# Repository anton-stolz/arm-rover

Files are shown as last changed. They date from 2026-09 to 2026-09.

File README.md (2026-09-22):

# Arm Rover



## Features
For now it can drive to specified positions on its map.

## Map



## Hardware

The Chassis is build with wood bars and a lot of hot glue

- RaspberryPi 4
- Arduino Uno
- 2D Lidar ld d500
- imu: mpu6500
- 5v 2A UBEC, 5v 8A UBEC
- DC Motor controller build from spare parts: Mosfet Transistor, logic Transistor and Relay
- Geard TT-Motors with wheels
- Hall Sensors 49E
- Battery: 2200mAh LiPo

## Wheel Encoders
Custom designed and 3d Printed magnetic encoder using 4 2x5mm Neodym magnets, aranged in a 4 Pole encoder.

## Bumper Sensor
the lidar is mounted relatively high, so there is a danger of bumping into stuff thats below the line of sight of the lidar sensor.
The Bumper sensors are the cardboard sheets in the front of back which are mounted with foam at the lower end, so it compresses, and using hall sensors this movement can be detected.  

## Software

all of this glue code is mostly written by LLMs, \
my contribution is the Integration, and actually making it work.

## In Progress: Robot Arm



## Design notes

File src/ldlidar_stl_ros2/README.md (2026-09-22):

- [cn](#操作指南)
- [en](#Instructions)
# 操作指南

>此SDK仅适用于深圳乐动机器人有限公司销售的激光雷达产品，产品型号为:
> - LDROBOT LiDAR LD06
> - LDROBOT LiDAR LD19
> - LDROBOT LiDAR STL-27L

## 0. 获取雷达的ROS2功能包
```bash
cd ~

mkdir -p ldlidar_ros2_ws/src

cd ldlidar_ros2_ws/src

git clone  https://github.com/ldrobotSensorTeam/ldlidar_stl_ros2.git
```
## 1. 系统设置
- 第一步，通过板载串口或者USB转串口模块(例如,cp2102模块)的方式使雷达连接到你的系统主板.
- 第二步，设置雷达在系统中挂载的串口设备-x权限(以/dev/ttyUSB0为例)
	- 实际使用时，根据雷达在你的系统中的实际挂载情况来设置，可以使用`ls -l /dev`命令查看.

``` bash
cd ~/ldlidar_ros2_ws

sudo chmod 777 /dev/ttyUSB0
```
- 第三步，修改`launch/`目录下雷达产品型号对应的lanuch文件中的`port_name`值，以`ld06.launch.py` 和 `/dev/ttyUSB0`为例，如下所示.

```py
#!/usr/bin/env python3
from launch import LaunchDescription
from launch_ros.actions import Node

'''
Parameter Description:
---
- Set laser scan directon: 
  1. Set counterclockwise, example: {'laser_scan_dir': True}
  2. Set clockwise,        example: {'laser_scan_dir': False}
- Angle crop setting, Mask data within the set angle range:
  1. Enable angle crop fuction:
    1.1. enable angle crop,  example: {'enable_angle_crop_func': True}
    1.2. disable angle crop, example: {'enable_angle_crop_func': False}
  2. Angle cropping interval setting:
  - The distance and intensity data within the set angle range will be set to 0.
  - angle >= 'angle_crop_min' and angle <= 'angle_crop_max' which is [angle_crop_min, angle_crop_max], unit is degress.
    example:
      {'angle_crop_min': 135.0}
      {'angle_crop_max': 225.0}
      which is [135.0, 225.0], angle unit is degress.
'''

def generate_launch_description():
  # LDROBOT LiDAR publisher node
  ldlidar_node = Node(
      package='ldlidar_stl_ros2',
      executable='ldlidar_stl_ros2_node',
      name='LD06',
      output='screen',
      parameters=[
        {'product_name': 'LDLiDAR_LD06'},
        {'topic_name': 'scan'},
        {'frame_id': 'base_laser'},
        {'port_name': '/dev/ttyUSB0'},
        {'port_baudrate': 230400},
        {'laser_scan_dir': True},
        {'enable_angle_crop_func': False},
        {'angle_crop_min': 135.0},
        {'angle_crop_max': 225.0}
      ]
  )

  # base_link to base_laser tf node
  base_link_to_laser_tf_node = Node(
    package='tf2_ros',
    executable='static_transform_publisher',
    name='base_link_to_base_laser_ld06',
    arguments=['0','0','0.18','0','0','0','base_link','base_laser']
  )

  # Define LaunchDescription variable
  ld = LaunchDescription()

  ld.add_action(ldlidar_node)
  ld.add_action(base_link_to_laser_tf_node)

  return ld
```
## 2. 编译方法

使用colcon编译.

```bash
cd ~/ldlidar_ros2_ws

colcon build
```
## 3. 运行方法
### 3.1. 设置功能包环境变量

- 编译完成后需要将编译生成的相关文件加入环境变量，便于 ROS 环境可以识别， 执行命令如下所示， 该命令是临时给终端加入环境变量，意味着您如果重新打开新的终端，也需要重新执行如下命令.

  ```bash
  cd ~/ldlidar_ros2_ws

  source install/setup.bash
  ```
- 为了重新打开终端后，永久不用执行上述添加环境变量的命令，可以进行如下操作.

  ```bash
  echo source ~/ldlidar_ros2_ws/install/setup.bash >> ~/.bashrc

  source ~/.bashrc
  ```
### 3.2. 启动激光雷达节点

- 产品型号为 LDROBOT LiDAR LD06
  - 启动ld06 lidar node:
  ``` bash
  ros2 launch ldlidar_stl_ros2 ld06.launch.py
  ```
  - 启动ld06 lidar node并显示激光数据在Rviz2上:
  ``` bash
  ros2 launch ldlidar_stl_ros2 viewer_ld06.launch.py
  ```

- 产品型号为 LDROBOT LiDAR LD19
  - 启动ld19 lidar node:
  ``` bash
  ros2 launch ldlidar_stl_ros2 ld19.launch.py
  ```
  - 启动ld19 lidar node并显示激光数据在Rviz2上:
  ``` bash
  ros2 launch ldlidar_stl_ros2 viewer_ld19.launch.py
  ```
  
- 产品型号为 LDROBOT LiDAR STL-27L
  - 启动stl27l lidar node:
  ``` bash
  ros2 launch ldlidar_stl_ros2 stl27l.launch.py
  ```
  - 启动stl27l lidar node并显示激光数据在Rviz2上:
  ``` bash
  ros2 launch ldlidar_stl_ros2 viewer_stl27l.launch.py
  ```

##   4. 测试

> 代码支持ubuntu20.04 ROS2 foxy版本及以上测试，使用rviz2可视化。
- 新打开一个终端 (Ctrl + Alt + T),运行命令:`rviz2`,并通过Rviz2工具打开readme文件所在目录的rviz2文件夹下面的ldlidar.rviz文件
```bash
rviz2
```

# Instructions

> This SDK is only applicable to the LiDAR products sold by Shenzhen LDROBOT Co., LTD. The product models are :
> - LDROBOT LiDAR LD06
> - LDROBOT LiDAR LD19
> - LDROBOT LiDAR STL-27L

## step 0: get LiDAR ROS2 Package
```bash
cd ~

mkdir -p ldlidar_ros2_ws/src

cd ldlidar_ros2_ws/src

git clone  https://github.com/ldrobotSensorTeam/ldlidar_stl_ros2.git
```
## step 1: system setup
- Connect the LiDAR to your system motherboard via an onboard serial port or usB-to-serial module (for example, CP2102 module).

- Set the -x permission for the serial port device mounted by the radar in the system (for example, /dev/ttyUSB0)

  - In actual use, the LiDAR can be set according to the actual mounted status of your system, you can use 'ls -l /dev' command to view.

``` bash
cd ~/ldlidar_ros2_ws

sudo chmod 777 /dev/ttyUSB0
```
- Modify the `port_name` value in the Lanuch file corresponding to the radar product model under `launch/`, using `ld06.launch.py` and `/dev/ttyUSB0` as an example, as shown below.

```py
#!/usr/bin/env python3
from launch import LaunchDescription
from launch_ros.actions import Node

'''
Parameter Description:
---
- Set laser scan directon: 
  1. Set counterclockwise, example: {'laser_scan_dir': True}
  2. Set clockwise,        example: {'laser_scan_dir': False}
- Angle crop setting, Mask data within the set angle range:
  1. Enable angle crop fuction:
    1.1. enable angle crop,  example: {'enable_angle_crop_func': True}
    1.2. disable angle crop, example: {'enable_angle_crop_func': False}
  2. Angle cropping interval setting:
  - The distance and intensity data within the set angle range will be set to 0.
  - angle >= 'angle_crop_min' and angle <= 'angle_crop_max' which is [angle_crop_min, angle_crop_max], unit is degress.
    example:
      {'angle_crop_min': 135.0}
      {'angle_crop_max': 225.0}
      which is [135.0, 225.0], angle unit is degress.
'''

def generate_launch_description():
  # LDROBOT LiDAR publisher node
  ldlidar_node = Node(
      package='ldlidar_stl_ros2',
      executable='ldlidar_stl_ros2_node',
      name='LD06',
      output='screen',
      parameters=[
        {'product_name': 'LDLiDAR_LD06'},
        {'topic_name': 'scan'},
        {'frame_id': 'base_laser'},
        {'port_name': '/dev/ttyUSB0'},
        {'port_baudrate': 230400},
        {'laser_scan_dir': True},
        {'enable_angle_crop_func': False},
        {'angle_crop_min': 135.0},
        {'angle_crop_max': 225.0}
      ]
  )

  # base_link to base_laser tf node
  base_link_to_laser_tf_node = Node(
    package='tf2_ros',
    executable='static_transform_publisher',
    name='base_link_to_base_laser_ld06',
    arguments=['0','0','0.18','0','0','0','base_link','base_laser']
  )

  # Define LaunchDescription variable
  ld = LaunchDescription()

  ld.add_action(ldlidar_node)
  ld.add_action(base_link_to_laser_tf_node)

  return ld
```

## step 2: build

Run the following command.

```bash
cd ~/ldlidar_ros2_ws

colcon build
```
## step 3: run

### step3.1: package environment variable settings

- After the compilation is completed, you need to add the relevant files generated by the compilation to the environment variables, so that the ROS environment can recognize them. The execution command is as follows. This command is to temporarily add environment variables to the terminal, which means that if you reopen a new terminal, you also need to re-execute it. The following command.
  
  ```bash
  cd ~/ldlidar_ros2_ws
  
  source install/setup.bash
  ```
  
- In order to never need to execute the above command to add environment variables after reopening the terminal, you can do the following.

  ```bash
  echo source ~/ldlidar_ros2_ws/install/setup.bash >> ~/.bashrc
  
  source ~/.bashrc
  ```
### step3.2: start LiDAR node

- The product is LDROBOT LiDAR LD06
  - start ld06 lidar node:
  ``` bash
  ros2 launch ldlidar_stl_ros2 ld06.launch.py
  ```
  - start ld06 lidar node and show on the Rviz2:
  ``` bash
  ros2 launch ldlidar_stl_ros2 viewer_ld06.launch.py
  ```

- The product is LDROBOT LiDAR LD19
  - start ld19 lidar node:
  ``` bash
  ros2 launch ldlidar_stl_ros2 ld19.launch.py
  ```
  - start ld19 lidar node and show on the Rviz2:
  ``` bash
  ros2 launch ldlidar_stl_ros2 viewer_ld19.launch.py
  ```
  
- The product is LDROBOT LiDAR STL-27L
  - start stl27l lidar node:
  ``` bash
  ros2 launch ldlidar_stl_ros2 stl27l.launch.py
  ```
  - start stl27l lidar node and show on the Rviz2:
  ``` bash
  ros2 launch ldlidar_stl_ros2 viewer_stl27l.launch.py
  ```

## step 4: test

> The code supports ubuntu 20.04 ros2 foxy version and above, using rviz2 visualization.

- new a terminal (Ctrl + Alt + T) and use Rviz2 tool(run command: `rviz2`) ,open the `ldlidar.rviz` file below the rviz2 folder of the readme file directory
```bash
rviz2
```
# arm-rover

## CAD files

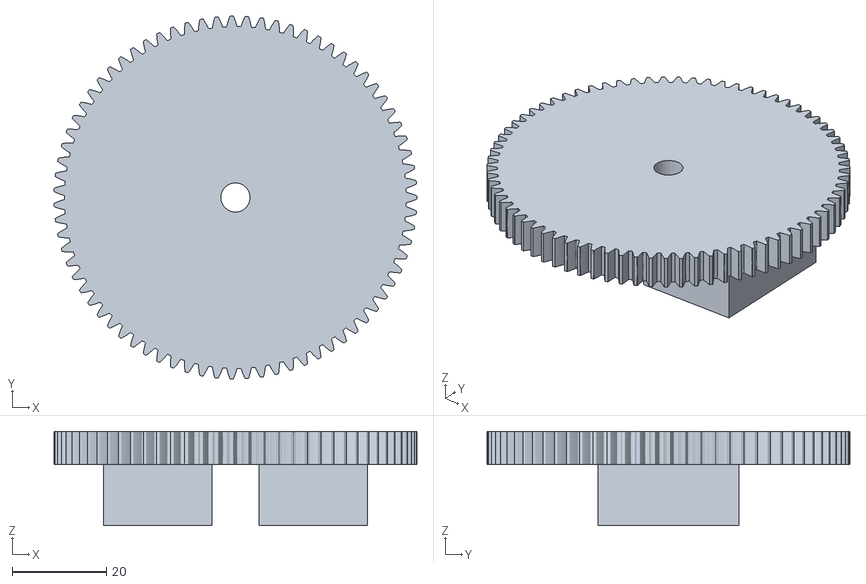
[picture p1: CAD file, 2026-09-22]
hardware/robot_arm/big_gear_with_wood_holder.stl
77.0 x 77.0 x 20.0

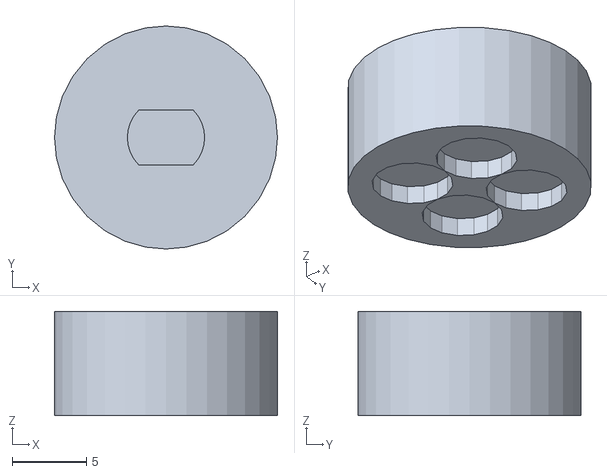
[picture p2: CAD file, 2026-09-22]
hardware/wheel_encoder/hall_wheel.stl
15.0 x 15.0 x 7.00

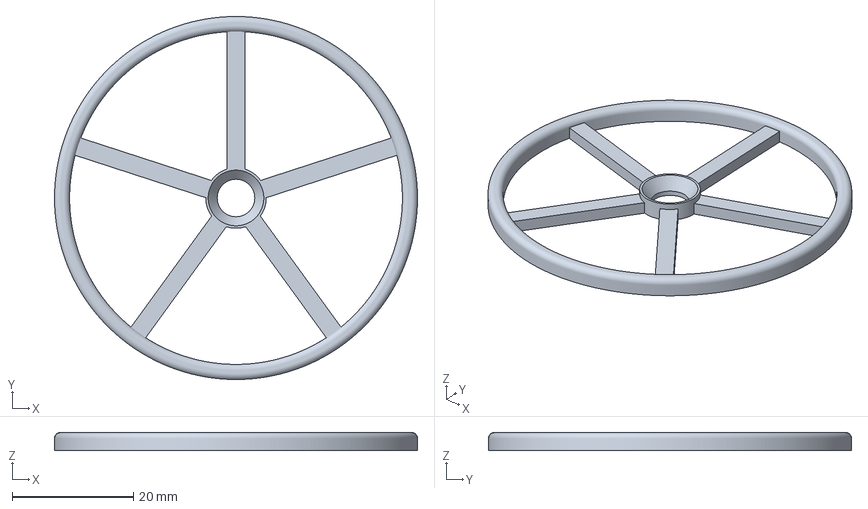
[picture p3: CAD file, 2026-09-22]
hardware/robot_arm/joint1_friction_circle-BodyChamfer.3mf
60.0 x 60.0 x 3.00 mm

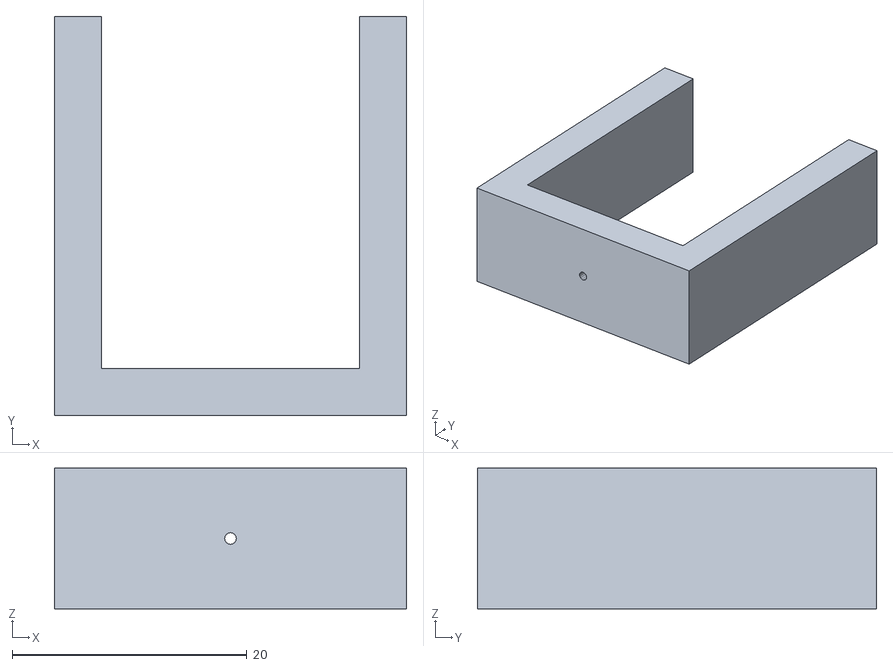
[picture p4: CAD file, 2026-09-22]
hardware/wheel_encoder/hall_holder.stl
30.0 x 34.0 x 12.0

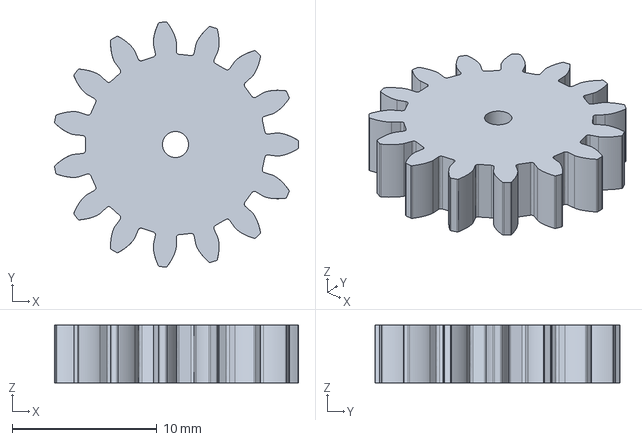
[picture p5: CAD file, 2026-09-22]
hardware/robot_arm/servo_gear.FCStd
16.9 x 16.9 x 4.00 mm

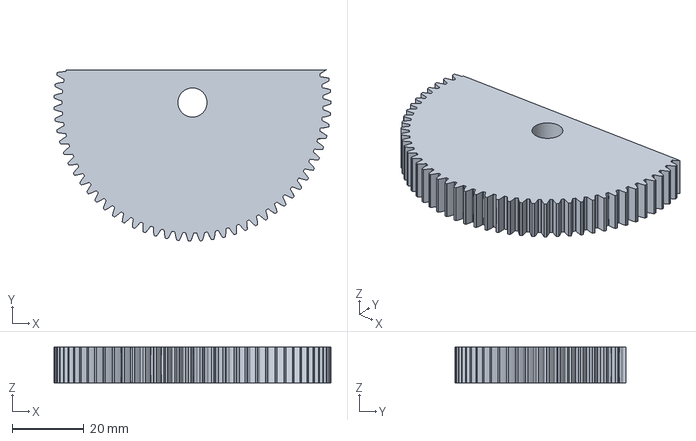
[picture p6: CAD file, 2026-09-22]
hardware/robot_arm/joint2.FCStd
77.0 x 47.5 x 10.0 mm

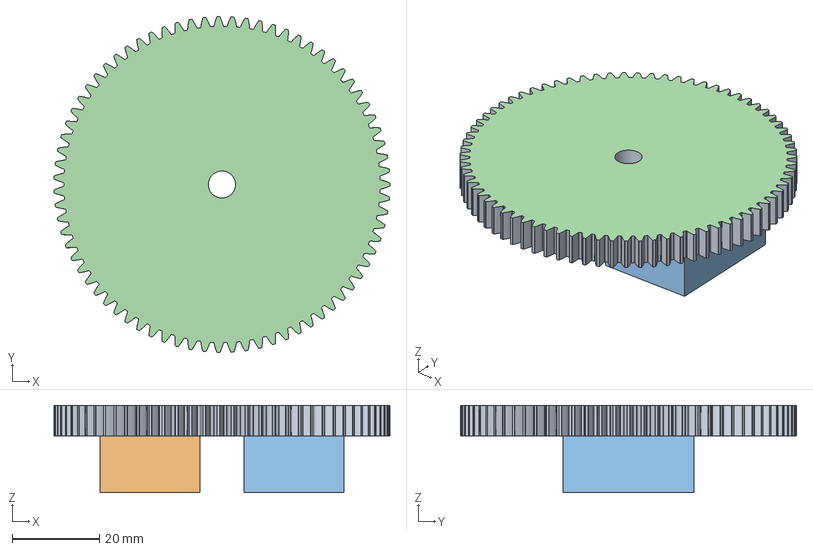
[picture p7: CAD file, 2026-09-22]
hardware/robot_arm/arm.FCStd
77.0 x 77.0 x 20.0 mm
gear_big
Extrude (Mirror #1)
ReferenceInvoluteGear001

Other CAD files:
hardware/robot_arm/joint1_friction_circle.FCStd
hardware/robot_arm/servo_gear-Cut.3mf

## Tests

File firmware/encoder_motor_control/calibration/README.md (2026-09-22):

# Clean Version: Magnetic Encoder Ultimate Synthesis

This folder contains the final, bug-free version of the advanced 5-parameter and 4Pi kinematic LUT calibration logic for the robot's magnetic encoders.

## Files
- `data/aufnahme_20260824_010724.csv`: The high-quality constant-speed recording used for calibration.
- `calibrate_and_plot.py`: The single, clean, highly readable Python script that performs the calibration and exports the results to a C++ header.
- `live_angle_plot.py`: A live visualization tool. Run this while the Arduino is plugged in to see a real-time plot of the fully synthesized, perfectly linear 0-360 degree angle output!
- `sensor_reader/sensor_reader.ino`: The raw Arduino data logger script used to stream the raw ADC values over serial.
- `encoder_decoder/encoder_decoder.ino`: The FINAL Arduino skeleton sketch. It includes the generated header and actually uses the math (5-parameter + LUT + Lissajous startup voting) to output continuous, highly accurate mechanical angle in real-time.
- `encoder_decoder/calib_constants.h`: The auto-generated PROGMEM header containing all calibration parameters (Generated by running the Python script).

## How it works
1. **5-Parameter Math (No LUT):** The script first fits a 5-parameter ellipse (offsets, amplitudes, and phase delta) to center and normalize the raw sensor data to a perfect unit circle.
2. **4Pi LUT (With LUT):** Because the magnets are not perfect and cause ripples in the speed, the script builds a 720-bin (4Pi electrical) kinematic velocity look-up table by assuming the macroscopic speed over 10 seconds is the "true" speed.
3. **Tracking & Silent Phase Correction:** Because 2-pole pair encoders have a 180-degree physical ambiguity, the Arduino takes a best-effort guess at boot and instantly starts outputting continuous angle data so your PID loop doesn't explode. Meanwhile, the Python script has calculated a "Safe Zone" (the electrical angle where the signatures are furthest apart). As the wheel turns, the Arduino waits until it hits this Safe Zone. It then verifies if its initial guess was right. If it guessed wrong, it silently flips the phase in the background and absorbs the jump in a display offset, meaning your ROS controller sees **perfectly continuous odometry with zero jumps**, but the ripple magically disappears mid-drive!

## Usage
1. Generate the calibration header from your CSV:
```bash
uv run python calibrate_and_plot.py
```
2. Flash `encoder_decoder/encoder_decoder.ino` to your Arduino.
3. The Arduino will instantly stream continuous data. You can watch the Serial monitor as you manually spin the wheels; it will print `[DEBUG]` messages confirming exactly when each wheel hits its safe zone and whether its initial boot guess was confirmed or corrected.
4. **Live Visualization:** Close the Arduino Serial Monitor and run:
```bash
uv run python live_angle_plot.py
```
This will open a live graphing window showing the fully corrected, perfectly linear sawtooth angle (mod 360) in real-time. (Note: It also prints the `[DEBUG]` homing messages to your console so you can see when the phases lock).

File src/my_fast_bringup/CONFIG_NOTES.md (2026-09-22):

# Configuration & Optimization Notes

## 1. Disabled Nav2 Servers (`navigation_launch.py`)
To save ~30% CPU on the Raspberry Pi 4, two unused servers were removed from `navigation_launch.py`:
- `route_server` (nav2_route)
- `docking_server` (opennav_docking)

**How to re-enable in the future if needed:**
In `launch/navigation_launch.py`:
1. Re-add `'route_server'` and `'docking_server'` to `lifecycle_nodes`.
2. Re-add the `Node(...)` definitions for `nav2_route` and `opennav_docking` to `load_nodes` (or composable list).

## 2. Collision Monitor Polygon (`config/nav2_params.yaml`)
- `PolygonStop`: Configured in `base_link` frame as `[[0.18, 0.18], [0.18, -0.18], [-0.18, -0.18], [-0.18, 0.18]]`.
- The physical robot chassis is 30x30 cm centered at the origin `base_link` (bounds: +/- 0.15 m).
- The 0.18 m boundary provides a 3 cm safety buffer around the perimeter.
- Sensor frames:
  - LiDAR is mounted at `x: 0.02 m`, `y: -0.04 m` (4 cm to the right), `z: 0.21 m`.
  - IMU is mounted at `x: 0.03 m`, `y: -0.06 m` (6 cm to the right), `z: 0.07 m`.
  - The `collision_monitor` uses TF to automatically transform laser scans into `base_link`, so the LiDAR offset is automatically accounted for.

## 3. Nav2 Dynamic Limits
- Controller: `RegulatedPurePursuitController` (RPP)
- `rotate_to_heading_angular_vel`: 1.0 rad/s (matches Lichtblick [-1, 1] limits)
- `max_velocity`: `[0.28, 0.0, 1.0]`
- `min_velocity`: `[-0.25, 0.0, -1.0]`

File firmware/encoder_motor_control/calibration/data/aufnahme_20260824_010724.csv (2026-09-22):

zeit_s | enc1_s1 | enc1_s2 | enc2_s1 | enc2_s2
0.000 | 252.0 | 343.0 | 731.0 | 698.0
0.006 | 247.0 | 352.0 | 731.0 | 717.0
0.013 | 242.0 | 360.0 | 730.0 | 735.0
0.019 | 239.0 | 369.0 | 728.0 | 750.0
0.026 | 236.0 | 379.0 | 724.0 | 766.0
0.032 | 234.0 | 390.0 | 719.0 | 780.0
0.038 | 232.0 | 402.0 | 712.0 | 793.0
0.045 | 231.0 | 411.0 | 705.0 | 804.0
0.051 | 230.0 | 424.0 | 695.0 | 814.0
0.057 | 230.0 | 437.0 | 683.0 | 824.0
0.063 | 230.0 | 450.0 | 673.0 | 830.0
0.070 | 231.0 | 464.0 | 663.0 | 834.0
0.077 | 232.0 | 476.0 | 654.0 | 835.0
0.083 | 235.0 | 491.0 | 643.0 | 838.0
0.089 | 238.0 | 506.0 | 630.0 | 840.0
0.095 | 241.0 | 520.0 | 615.0 | 840.0
0.101 | 245.0 | 536.0 | 599.0 | 841.0
0.108 | 251.0 | 550.0 | 584.0 | 840.0
0.115 | 257.0 | 565.0 | 567.0 | 841.0
0.121 | 263.0 | 579.0 | 553.0 | 841.0
0.127 | 268.0 | 595.0 | 533.0 | 840.0
0.133 | 280.0 | 609.0 | 515.0 | 838.0
0.140 | 289.0 | 623.0 | 497.0 | 837.0
0.146 | 298.0 | 634.0 | 481.0 | 833.0
0.152 | 303.0 | 647.0 | 465.0 | 828.0
0.159 | 316.0 | 660.0 | 446.0 | 822.0
0.165 | 329.0 | 670.0 | 427.0 | 814.0
0.172 | 340.0 | 681.0 | 409.0 | 803.0
0.178 | 349.0 | 691.0 | 393.0 | 790.0
0.184 | 365.0 | 701.0 | 377.0 | 775.0
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

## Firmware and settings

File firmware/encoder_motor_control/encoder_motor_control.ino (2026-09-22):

// ============================================================
//  FINAL: Encoder + PI + Motorsteuerung + binäres Protokoll
//  - Active-low relays: OFF = HIGH, ON = LOW
//  - Safe relay init: pins go HIGH as early as possible
//  - Raw bumper ADC values always in telemetry
//  - Simplified per-wheel state machine (no cross-wheel sync)
// ============================================================

#include "calib_constants.h"
#include <avr/pgmspace.h>
#include <math.h>

// ============================================================
//  FORWARD DECLARATIONS 
// ============================================================
struct WheelController;
void motorOff(WheelController* wc);
void motorSetDuty(WheelController* wc, uint8_t duty);
void motorSetDir(WheelController* wc, int8_t dir);
void updateMotorController(WheelController* wc, float dt_ms);

// ---------------- Pins ----------------
const int PIN_ENC1_S1 = A0;   // links
const int PIN_ENC1_S2 = A1;
const int PIN_ENC2_S1 = A2;   // rechts
const int PIN_ENC2_S2 = A3;

const int PIN_BUMPER_LEFT = A4;
const int PIN_BUMPER_RIGHT = A5;

struct Motor {
    uint8_t pwm, rlyA, rlyB;
    const char* name;
};

Motor LEFT_MOTOR  = { 11, 10, 9, "L" };
Motor RIGHT_MOTOR = { 3, 4, 5, "R" };

// ================= SIGN CALIBRATION =================
const int8_t LEFT_MOTOR_SIGN   = -1;
const int8_t RIGHT_MOTOR_SIGN  = -1;
const int8_t LEFT_ENCODER_SIGN = 1;
const int8_t RIGHT_ENCODER_SIGN = 1;
// ====================================================

// Active-low relay module:
// LOW  -> relay ON
// HIGH -> relay OFF
const bool RELAY_ON  = LOW;
const bool RELAY_OFF = HIGH;

const uint8_t MOTOR_MIN_DUTY = 55;      // Deadzone
const uint8_t MOTOR_MAX_DUTY = 255;
const float MAX_TARGET_DEG_S = 720.0;

float KP = 0.15;
float KI = 0.8;
const float INTEGRAL_LIMIT = 200.0;

// Combined relay switching delay (back-EMF decay + relay settle)
const unsigned long RELAY_SWITCH_MS = 150;

const unsigned long CMD_WATCHDOG_MS = 500;
unsigned long last_valid_cmd_ms = 0;

// ---------------- Encoder ----------------
struct EncoderState {
    const char* name;
    float o1, o2, a1, a2, delta;
    const float* lut;
    const float* lissajous_s1;
    const float* lissajous_s2;
    int safe_angle_idx;
    bool safe_zone_verified;
    float unwrapped_phase;
    float last_raw_angle;
    float display_offset;
    float continuous_angle_deg;
    bool first_update;
    float last_continuous_angle;
    float velocity_deg_s;
};

EncoderState enc1 = {
    "Enc1", ENC1_O1, ENC1_O2, ENC1_A1, ENC1_A2, ENC1_DELTA,
    ENC1_LUT, ENC1_LISSAJOUS_S1, ENC1_LISSAJOUS_S2, ENC1_SAFE_ANGLE_IDX,
    false, 0.0, 0.0, 0.0, 0.0, true, 0.0, 0.0
};

EncoderState enc2 = {
    "Enc2", ENC2_O1, ENC2_O2, ENC2_A1, ENC2_A2, ENC2_DELTA,
    ENC2_LUT, ENC2_LISSAJOUS_S1, ENC2_LISSAJOUS_S2, ENC2_SAFE_ANGLE_IDX,
    false, 0.0, 0.0, 0.0, 0.0, true, 0.0, 0.0
};

int safeAnalogRead(int pin) {
    analogRead(pin);       // dummy read to settle ADC mux
    return analogRead(pin);
}

float get_raw_phase(EncoderState* enc, int s1, int s2) {
    float x = (s1 - enc->o1) / enc->a1;
    float y = (s2 - enc->o2) / enc->a2;
    float sin_d = sin(enc->delta);
    float cos_d = cos(enc->delta);
    float y_corr = (y - x * sin_d) / cos_d;
    return atan2(y_corr, x);
}

float read_progmem_float(const float* array, int index) {
    float val;
    memcpy_P(&val, &array[index], sizeof(float));
    return val;
}

void init_encoder_start(EncoderState* enc, int pin_s1, int pin_s2) {
    float err_0 = 0, err_2pi = 0;
    int valid0 = 0, valid2pi = 0;

    for (int i = 0; i < 20; i++) {
        int s1 = safeAnalogRead(pin_s1);
        int s2 = safeAnalogRead(pin_s2);
        float ang = get_raw_phase(enc, s1, s2);

        float d0 = fmod(ang, 4.0 * PI);
        if (d0 < 0) d0 += 4.0 * PI;
        int i0 = (int)((d0 / (4.0 * PI)) * 720) % 720;

        float d2 = fmod(ang + 2.0 * PI, 4.0 * PI);
        if (d2 < 0) d2 += 4.0 * PI;
        int i2 = (int)((d2 / (4.0 * PI)) * 720) % 720;

        float e1 = read_progmem_float(enc->lissajous_s1, i0);
        float e2 = read_progmem_float(enc->lissajous_s2, i0);
        if (e1 > -0.5 && e2 > -0.5) {
            err_0 += (e1 - s1) * (e1 - s1) + (e2 - s2) * (e2 - s2);
            valid0++;
        }

        float f1 = read_progmem_float(enc->lissajous_s1, i2);
        float f2 = read_progmem_float(enc->lissajous_s2, i2);
        if (f1 > -0.5 && f2 > -0.5) {
            err_2pi += (f1 - s1) * (f1 - s1) + (f2 - s2) * (f2 - s2);
            valid2pi++;
        }

        delay(2);
    }

    enc->unwrapped_phase = (valid0 > 0 && valid2pi > 0 && err_2pi < err_0) ? 2.0 * PI : 0.0;
    enc->last_raw_angle = get_raw_phase(enc, safeAnalogRead(pin_s1), safeAnalogRead(pin_s2));
    enc->display_offset = 0.0;
    enc->safe_zone_verified = false;
    enc->continuous_angle_deg = 0.0;
    enc->last_continuous_angle = 0.0;
    enc->velocity_deg_s = 0.0;
    enc->first_update = true;
}

void update_encoder(EncoderState* enc, int s1, int s2, float dt) {
    float ang = get_raw_phase(enc, s1, s2);
    float diff = ang - enc->last_raw_angle;

    if (diff > PI) enc->unwrapped_phase -= 2.0 * PI;
    else if (diff < -PI) enc->unwrapped_phase += 2.0 * PI;

    enc->last_raw_angle = ang;

    float d_phase = fmod(ang + enc->unwrapped_phase, 4.0 * PI);
    if (d_phase < 0) d_phase += 4.0 * PI;
    int idx = (int)((d_phase / (4.0 * PI)) * 720) % 720;

    if (!enc->safe_zone_verified) {
        int cur = idx % 360;
        int dist = abs(cur - enc->safe_angle_idx);
        if (dist > 180) dist = 360 - dist;

        if (dist <= 10) {
            float e1 = read_progmem_float(enc->lissajous_s1, cur);
            float e2 = read_progmem_float(enc->lissajous_s2, cur);
            float f1 = read_progmem_float(enc->lissajous_s1, cur + 360);
            float f2 = read_progmem_float(enc->lissajous_s2, cur + 360);

            float err0 = (e1 - s1) * (e1 - s1) + (e2 - s2) * (e2 - s2);
            float err2 = (f1 - s1) * (f1 - s1) + (f2 - s2) * (f2 - s2);

            bool cur_is_0 = (idx < 360);
            bool true_is_0 = (err0 <= err2);

            if (cur_is_0 != true_is_0) {
                if (cur_is_0) {
                    enc->unwrapped_phase += 2.0 * PI;
                    enc->display_offset -= 180.0;
                } else {
                    enc->unwrapped_phase -= 2.0 * PI;
                    enc->display_offset += 180.0;
                }
            }

            enc->safe_zone_verified = true;

            d_phase = fmod(ang + enc->unwrapped_phase, 4.0 * PI);
            if (d_phase < 0) d_phase += 4.0 * PI;
            idx = (int)((d_phase / (4.0 * PI)) * 720) % 720;
        }
    }

    int wraps = (int)floor((ang + enc->unwrapped_phase) / (4.0 * PI));
    float bin_float = (d_phase / (4.0 * PI)) * 720.0;
    int idx1 = ((int)bin_float) % 720;
    int idx2 = (idx1 + 1) % 720;
    float frac = bin_float - (int)bin_float;

    float lut1 = read_progmem_float(enc->lut, idx1);
    float lut2 = read_progmem_float(enc->lut, idx2);

    float lut_diff = lut2 - lut1;
    if (lut_diff < -PI) lut_diff += 2.0 * PI;
    if (lut_diff > PI) lut_diff -= 2.0 * PI;

    float lut_val = lut1 + frac * lut_diff;

    enc->continuous_angle_deg = ((wraps * 2.0 * PI) + lut_val) * (180.0 / PI) + enc->display_offset;

    if (enc->first_update) {
        enc->last_continuous_angle = enc->continuous_angle_deg;
        enc->first_update = false;
    } else if (dt > 0.0) {
        float raw_vel = (enc->continuous_angle_deg - enc->last_continuous_angle) / dt;
        enc->velocity_deg_s = 0.2 * raw_vel + 0.8 * enc->velocity_deg_s;
        enc->last_continuous_angle = enc->continuous_angle_deg;
    }
}

// ---------------- Motor State Machine ----------------
// Simplified: 3 states, no cross-wheel synchronization.
//   IDLE      – motor off, relays don't matter
//   SWITCHING – PWM off, relays being set, waiting for settle
//   RUNNING   – PI controller active
enum MotorState {
    MOTOR_IDLE,
    MOTOR_SWITCHING,
    MOTOR_RUNNING
};

struct WheelController {
    Motor* motor;
    EncoderState* encoder;
    int8_t motor_sign;
    int8_t encoder_sign;
    float target_deg_s;
    float measured_deg_s;
    float kp, ki, integral;
    uint8_t pwm_duty;
    int8_t active_dir;      // current relay direction (1, -1, or 0=off)
    int8_t desired_dir;     // direction we want to switch to
    MotorState state;
    unsigned long switch_start_ms;
};

WheelController left_ctrl = {
    &LEFT_MOTOR,
    &enc1,
    LEFT_MOTOR_SIGN,
    LEFT_ENCODER_SIGN,
    0, 0,
    KP, KI,
    0,
    0, 0,
    MOTOR_IDLE,
    0
};

WheelController right_ctrl = {
    &RIGHT_MOTOR,
    &enc2,
    RIGHT_MOTOR_SIGN,
    RIGHT_ENCODER_SIGN,
    0, 0,
    KP, KI,
    0,
    0, 0,
    MOTOR_IDLE,
    0
};

// ---------------- Relay / PWM init ----------------
void relayInitPin(uint8_t pin) {
    // Safe init for active-low relay:
    // set HIGH before making the pin an output.
    digitalWrite(pin, RELAY_OFF);
    pinMode(pin, OUTPUT);
    digitalWrite(pin, RELAY_OFF);
}

void pwmInitPin(uint8_t pin) {
    // Inverted PWM in this project:
    // analogWrite(255) means OFF.
    digitalWrite(pin, HIGH);
    pinMode(pin, OUTPUT);
    analogWrite(pin, 255);
}

void relaySet(uint8_t pin, bool on) {
    digitalWrite(pin, on ? RELAY_ON : RELAY_OFF);
}

void motorOff(WheelController* wc) {
    analogWrite(wc->motor->pwm, 255);
}

void motorSetDuty(WheelController* wc, uint8_t duty) {
    wc->pwm_duty = duty;
    analogWrite(wc->motor->pwm, 255 - duty);
}

void motorSetDir(WheelController* wc, int8_t dir) {
    relaySet(wc->motor->rlyA, dir == 1);
    relaySet(wc->motor->rlyB, dir == -1);
    wc->active_dir = dir;
}

// Compute the relay direction needed for a given target speed.
int8_t targetToRelayDir(WheelController* wc, float target) {
    if (target == 0.0) return 0;
    int8_t s = (target > 0) ? 1 : -1;
    return (int8_t)(s * wc->motor_sign);
}

void updateMotorController(WheelController* wc, float dt_ms) {
    unsigned long now_ms = millis();
    wc->measured_deg_s = wc->encoder->velocity_deg_s * wc->encoder_sign;

    int8_t needed_dir = targetToRelayDir(wc, wc->target_deg_s);

    switch (wc->state) {
        case MOTOR_IDLE:
            if (wc->target_deg_s == 0.0) {
                // Stay idle.
                break;
            }
            // Need to start moving.
            wc->integral = 0.0;
            if (needed_dir == wc->active_dir && wc->active_dir != 0) {
                // Relays already in the right position, go straight to running.
                wc->state = MOTOR_RUNNING;
            } else {
                // Need to set/change relays.
                motorOff(wc);
                wc->pwm_duty = 0;
                wc->desired_dir = needed_dir;
                motorSetDir(wc, needed_dir);
                wc->switch_start_ms = now_ms;
                wc->state = MOTOR_SWITCHING;
            }
            break;

        case MOTOR_SWITCHING:
            // While switching, accept updated direction without restarting timer
            // (only restart if the desired direction actually changed).
            if (wc->target_deg_s == 0.0) {
                // Target went to zero while switching — just go idle.
                motorOff(wc);
                wc->pwm_duty = 0;
                wc->state = MOTOR_IDLE;
                break;
            }
            if (needed_dir != wc->desired_dir) {
                // Direction changed during switch — update relays and restart timer.
                wc->desired_dir = needed_dir;
                motorSetDir(wc, needed_dir);
                wc->switch_start_ms = now_ms;
            }
            if (now_ms - wc->switch_start_ms >= RELAY_SWITCH_MS) {
                wc->integral = 0.0;
                wc->state = MOTOR_RUNNING;
            }
            break;

        case MOTOR_RUNNING: {
            if (wc->target_deg_s == 0.0) {
                motorOff(wc);
                wc->integral = 0.0;
                wc->pwm_duty = 0;
                wc->state = MOTOR_IDLE;
                break;
            }

            // Check if direction change is needed.
            if (needed_dir != wc->active_dir) {
                motorOff(wc);
                wc->pwm_duty = 0;
                wc->integral = 0.0;
                wc->desired_dir = needed_dir;
                motorSetDir(wc, needed_dir);
                wc->switch_start_ms = now_ms;
                wc->state = MOTOR_SWITCHING;
                break;
            }

            // PI control.
            float target_mag = fabs(wc->target_deg_s);
            float s = (wc->target_deg_s > 0) ? 1.0 : -1.0;
            float measured_mag = wc->measured_deg_s * s;

            float ff = MOTOR_MIN_DUTY
                     + (target_mag / MAX_TARGET_DEG_S) * (MOTOR_MAX_DUTY - MOTOR_MIN_DUTY);

            float error = target_mag - measured_mag;
            wc->integral += error * dt_ms * 0.001;
            wc->integral = constrain(wc->integral, -INTEGRAL_LIMIT, INTEGRAL_LIMIT);

            float out = ff + wc->kp * error + wc->ki * wc->integral;
            motorSetDuty(wc, (uint8_t)constrain(out, 0.0, 255.0));
            break;
        }
    }
}

// ---------------- Binary Protocol ----------------
struct __attribute__((packed)) CmdPacket {
    uint8_t magic1, magic2;
    int16_t left_dps10, right_dps10;
    uint8_t checksum;
};

struct __attribute__((packed)) TelemetryPacket {
    uint8_t magic1, magic2;
    uint32_t time_ms;
    float left_angle_deg, right_angle_deg;
    float left_vel_deg_s, right_vel_deg_s;
    int16_t left_target_dps10, right_target_dps10;
    uint8_t left_pwm, right_pwm;
    uint8_t state_left, state_right;
    uint16_t raw_bumper_left;
    uint16_t raw_bumper_right;
    uint8_t checksum;
};

uint8_t calcChecksum(const uint8_t* data, size_t len) {
    uint8_t sum = 0;
    for (size_t i = 0; i < len - 1; i++) {
        sum += data[i];
    }
    return sum;
}

uint8_t cmd_buffer[sizeof(CmdPacket)];
size_t cmd_pos = 0;

void processSerial() {
    while (Serial.available()) {
        uint8_t b = Serial.read();

        if (cmd_pos == 0) {
            if (b == 0xAA) {
                cmd_buffer[0] = b;
                cmd_pos = 1;
            }
        } else {
            if (b == 0xAA && cmd_pos == 1) {
                cmd_buffer[0] = b;
                cmd_pos = 1;
            } else {
                cmd_buffer[cmd_pos++] = b;

                if (cmd_pos >= sizeof(CmdPacket)) {
                    CmdPacket* cmd = (CmdPacket*)cmd_buffer;

                    if (cmd->magic2 == 0x55 &&
                        cmd->checksum == calcChecksum(cmd_buffer, sizeof(CmdPacket))) {

                        left_ctrl.target_deg_s =
                            constrain(cmd->left_dps10 / 10.0, -MAX_TARGET_DEG_S, MAX_TARGET_DEG_S);

                        right_ctrl.target_deg_s =
                            constrain(cmd->right_dps10 / 10.0, -MAX_TARGET_DEG_S, MAX_TARGET_DEG_S);

                        last_valid_cmd_ms = millis();
                    }

                    cmd_pos = 0;
                }
            }
        }
    }
}

unsigned long last_telemetry_ms = 0;

void sendTelemetry() {
    unsigned long now = millis();

    if (now - last_telemetry_ms < 20) return;
    last_telemetry_ms = now;

    TelemetryPacket pkt;

    pkt.magic1 = 0xAB;
    pkt.magic2 = 0xCD;
    pkt.time_ms = now;

    pkt.left_angle_deg  = enc1.continuous_angle_deg;
    pkt.right_angle_deg = enc2.continuous_angle_deg;

    pkt.left_vel_deg_s  = left_ctrl.measured_deg_s;
    pkt.right_vel_deg_s = right_ctrl.measured_deg_s;

    pkt.left_target_dps10  = (int16_t)(left_ctrl.target_deg_s * 10.0);
    pkt.right_target_dps10 = (int16_t)(right_ctrl.target_deg_s * 10.0);

    pkt.left_pwm  = left_ctrl.pwm_duty;
    pkt.right_pwm = right_ctrl.pwm_duty;

    pkt.state_left  = left_ctrl.state;
    pkt.state_right = right_ctrl.state;

    pkt.raw_bumper_left  = (uint16_t)safeAnalogRead(PIN_BUMPER_LEFT);
    pkt.raw_bumper_right = (uint16_t)safeAnalogRead(PIN_BUMPER_RIGHT);

    pkt.checksum = calcChecksum((uint8_t*)&pkt, sizeof(pkt));

    Serial.write((uint8_t*)&pkt, sizeof(pkt));
}

// ---------------- Setup / Loop ----------------
unsigned long last_time = 0;

void setup() {
    Serial.begin(115200);

    // PWM pins first, in OFF state.
    pwmInitPin(LEFT_MOTOR.pwm);
    pwmInitPin(RIGHT_MOTOR.pwm);

    // Relay pins safe init: active-low relays off = HIGH.
    relayInitPin(LEFT_MOTOR.rlyA);
    relayInitPin(LEFT_MOTOR.rlyB);
    relayInitPin(RIGHT_MOTOR.rlyA);
    relayInitPin(RIGHT_MOTOR.rlyB);

    // Explicitly turn everything off.
    motorOff(&left_ctrl);
    motorOff(&right_ctrl);

    relaySet(LEFT_MOTOR.rlyA, false);
    relaySet(LEFT_MOTOR.rlyB, false);
    relaySet(RIGHT_MOTOR.rlyA, false);
    relaySet(RIGHT_MOTOR.rlyB, false);

    // Bumper analog inputs.
    pinMode(PIN_BUMPER_LEFT, INPUT);
    pinMode(PIN_BUMPER_RIGHT, INPUT);

    init_encoder_start(&enc1, PIN_ENC1_S1, PIN_ENC1_S2);
    init_encoder_start(&enc2, PIN_ENC2_S1, PIN_ENC2_S2);

    last_time = micros();
    last_valid_cmd_ms = millis();
}

void loop() {
    unsigned long now = micros();
    float dt_ms = (now - last_time) / 1000.0;
    last_time = now;

    processSerial();

    if (millis() - last_valid_cmd_ms > CMD_WATCHDOG_MS) {
        left_ctrl.target_deg_s = 0.0;
        right_ctrl.target_deg_s = 0.0;
    }

    update_encoder(
        &enc1,
        safeAnalogRead(PIN_ENC1_S1),
        safeAnalogRead(PIN_ENC1_S2),
        dt_ms * 0.001
    );

    update_encoder(
        &enc2,
        safeAnalogRead(PIN_ENC2_S1),
        safeAnalogRead(PIN_ENC2_S2),
        dt_ms * 0.001
    );

    updateMotorController(&left_ctrl, dt_ms);
    updateMotorController(&right_ctrl, dt_ms);

    sendTelemetry();
}

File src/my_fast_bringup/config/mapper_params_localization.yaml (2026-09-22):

slam_toolbox:
  ros__parameters:
    angle_variance_penalty: 0.3
    base_frame: base_link
    ceres_dogleg_type: TRADITIONAL_DOGLEG
    ceres_linear_solver: SPARSE_NORMAL_CHOLESKY
    ceres_loss_function: None
    ceres_preconditioner: SCHUR_JACOBI
    ceres_trust_strategy: LEVENBERG_MARQUARDT
    check_min_dist_and_heading_precisely: false
    coarse_angle_resolution: 0.02
    coarse_search_angle_offset: 1.05
    correlation_search_space_dimension: 1.2
    correlation_search_space_resolution: 0.02
    correlation_search_space_smear_deviation: 0.1
    debug_logging: false
    distance_variance_penalty: 0.2
    do_loop_closing: false
    enable_interactive_mode: false
    fine_search_angle_offset: 0.00349
    link_match_minimum_response_fine: 0.1
    link_scan_maximum_distance: 1.5
    loop_match_maximum_variance_coarse: 3.0
    loop_match_minimum_chain_size: 10
    loop_match_minimum_response_coarse: 0.45
    loop_match_minimum_response_fine: 0.55
    loop_search_maximum_distance: 3.0
    loop_search_space_dimension: 8.0
    loop_search_space_resolution: 0.05
    loop_search_space_smear_deviation: 0.03
    map_file_name: /home/anton/ros2_ws/src/my_fast_bringup/maps/complete_map
    map_frame: map
    map_start_pose:
    - -2.326
    - 0.246
    - 0.125
    map_update_interval: 5.0
    max_laser_range: 10.0
    min_laser_range: 0.0
    min_pass_through: 2
    minimum_angle_penalty: 0.4
    minimum_distance_penalty: 0.2
    minimum_time_interval: 0.05
    minimum_travel_distance: 0.05
    minimum_travel_heading: 0.05
    mode: localization
    occupancy_threshold: 0.1
    odom_frame: odom
    resolution: 0.05
    restamp_tf: false
    scan_buffer_maximum_scan_distance: 10.0
    scan_buffer_size: 10
    scan_topic: /scan
    solver_plugin: solver_plugins::CeresSolver
    stack_size_to_use: 40000000
    tf_buffer_duration: 30.0
    throttle_scans: 1
    transform_publish_period: 0.05
    transform_timeout: 0.5
    use_map_saver: false
    use_response_expansion: true
    use_scan_barycenter: true
    use_scan_matching: true

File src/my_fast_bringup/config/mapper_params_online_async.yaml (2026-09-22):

slam_toolbox:
  ros__parameters:

    # Plugin params
    solver_plugin: solver_plugins::CeresSolver
    ceres_linear_solver: SPARSE_NORMAL_CHOLESKY
    ceres_preconditioner: SCHUR_JACOBI
    ceres_trust_strategy: LEVENBERG_MARQUARDT
    ceres_dogleg_type: TRADITIONAL_DOGLEG
    ceres_loss_function: None

    # ROS Parameters
    odom_frame: odom
    map_frame: map
    base_frame: base_link
    scan_topic: /scan
    use_map_saver: false
    mode: mapping #localization

    debug_logging: false
    throttle_scans: 1
    transform_publish_period: 0.02 
    map_update_interval: 2.0
    resolution: 0.02
    restamp_tf: false
    min_laser_range: 0.15
    max_laser_range: 20.0 
    
    minimum_time_interval: 0.1
    transform_timeout: 0.5
    tf_buffer_duration: 30.0
    stack_size_to_use: 40000000
    enable_interactive_mode: false

    # General Parameters
    use_scan_matching: true
    use_scan_barycenter: true
    
    minimum_travel_distance: 0.3
    minimum_travel_heading: 0.3
    check_min_dist_and_heading_precisely: false
    
    scan_buffer_size: 15
    scan_buffer_maximum_scan_distance: 10.0
    link_match_minimum_response_fine: 0.1
    link_scan_maximum_distance: 1.5
    
    # Loop closure parameters
    loop_search_maximum_distance: 3.0
    do_loop_closing: true
    loop_match_minimum_chain_size: 10
    loop_match_maximum_variance_coarse: 3.0
    loop_match_minimum_response_coarse: 0.45
    loop_match_minimum_response_fine: 0.55

    # Correlation Parameters
    correlation_search_space_dimension: 0.5
    correlation_search_space_resolution: 0.01
    correlation_search_space_smear_deviation: 0.1

    # Loop Closure Parameters
    loop_search_space_dimension: 8.0
    loop_search_space_resolution: 0.05
    loop_search_space_smear_deviation: 0.03

    # Scan Matcher Parameters
    distance_variance_penalty: 0.5
    angle_variance_penalty: 1.0

    fine_search_angle_offset: 0.00349
    coarse_search_angle_offset: 0.80
    coarse_angle_resolution: 0.0349
    minimum_angle_penalty: 0.9
    minimum_distance_penalty: 0.5
    use_response_expansion: true
    min_pass_through: 2
    occupancy_threshold: 0.1

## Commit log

2026-09-22 Update README with corrections and new sections
    Corrected capitalization and improved clarity in the README. Added sections for Wheel Encoders and Bumper Sensor.
2026-09-22 added 3d model files from the wheel encoder parts
    [hall_holder.stl, hall_wheel.stl]
